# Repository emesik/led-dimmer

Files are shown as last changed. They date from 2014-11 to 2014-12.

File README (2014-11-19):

LED lighting dimmer

My aim was to create a dimmer for a long LED stripe which would go around a big room. I didn't
want to output raw PWM and have around 20m of cable acting as antenna, even though the frequency
could be low and theoretically harmless. For that reason the circuit has two modules:

	1. PWM generator with ATtiny85 microcontroller, two MOSFETs and potentiometer input
	2. LC filter with cutoff frequency just a bit above 150Hz

The final output is flat voltage depending on the PWM duty cycle. There is possibility, however, to
bypass the filter.

I used DTP-24 ferrite powder ring choke, rated up to 6A. That limits the circuit to 72W output.
The main MOSFET allows even 12A of continuous output at 25°C, so the max power depends mostly on
the choke you choose.

TODO:
	* So far tested it with tiny load. Must see how it behaves with a few meters of LED stripe.
	* The table of potentiometer to PWM duty cycle translation is still far from perfect and fails
	  to provide linear dimming.

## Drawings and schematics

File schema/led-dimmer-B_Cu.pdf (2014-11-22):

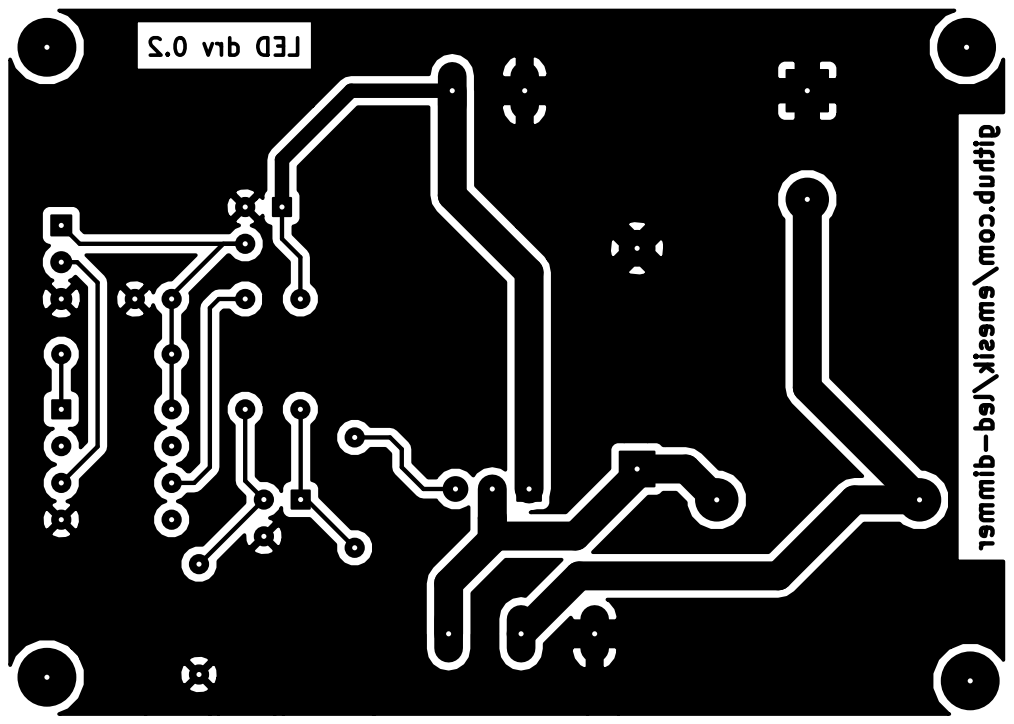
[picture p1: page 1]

github.com/emesik/led-dimmer LED drv 0.2

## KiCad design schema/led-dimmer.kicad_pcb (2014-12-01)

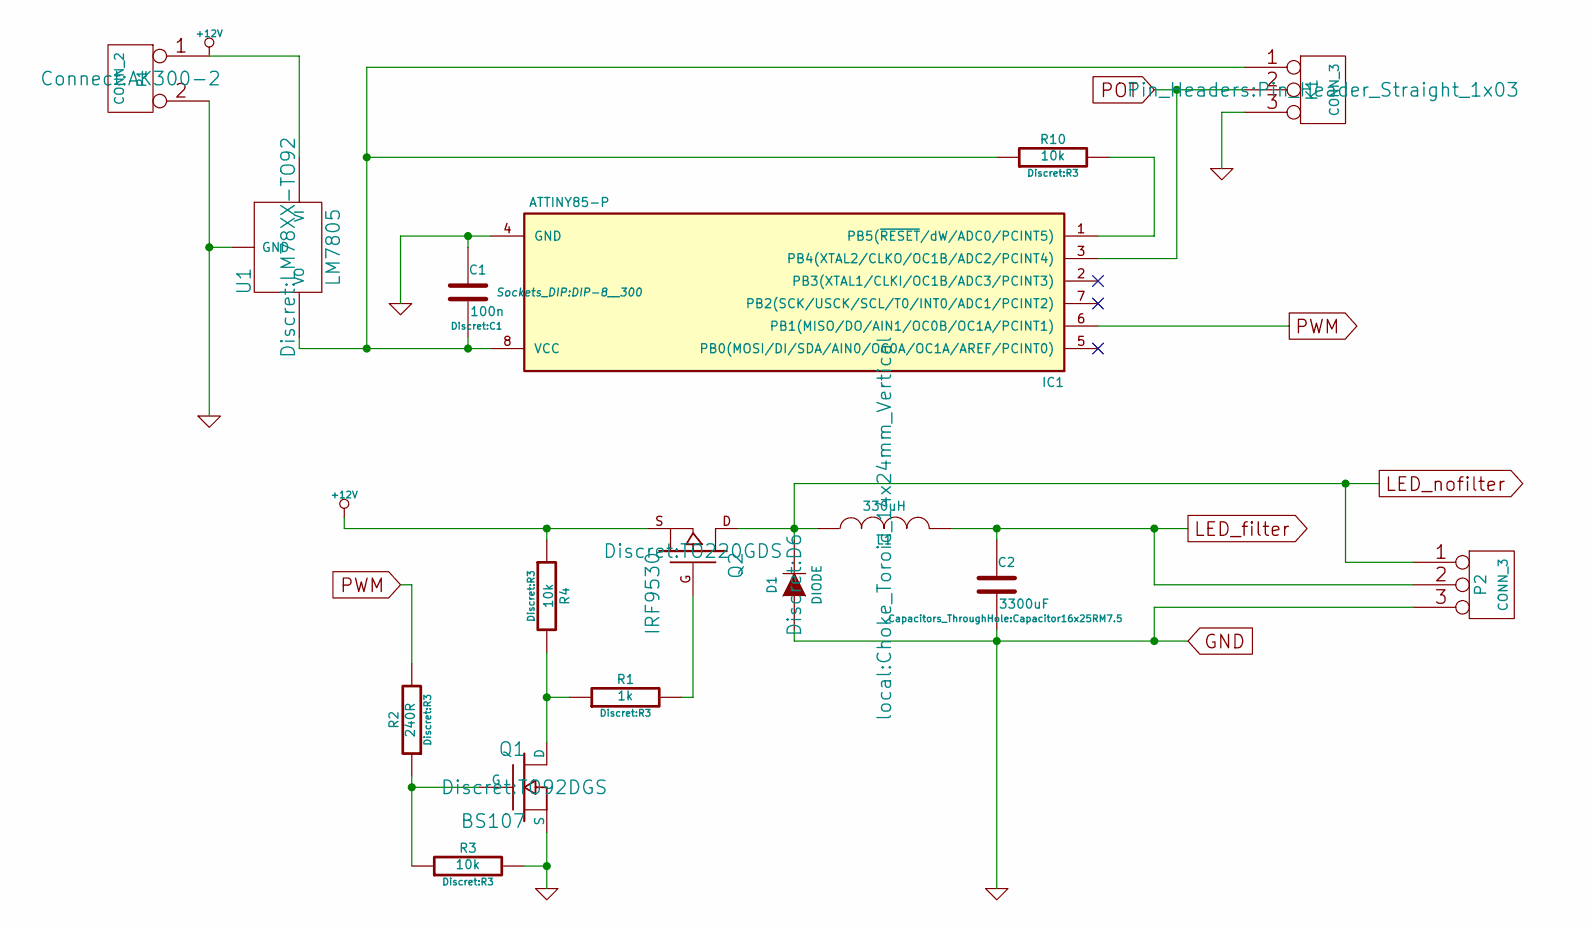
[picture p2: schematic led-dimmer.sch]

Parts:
C1: 100n; C1
C2: 3300uF; Capacitor16x25RM7.5
D1: DIODE; D6
IC1: ATTINY85-P; DIP-8__300
K1: CONN_3; Pin_Header_Straight_1x03
L1: 330uH; Choke_Toroid_14x24mm_Vertical
P1: CONN_2; AK300-2
P2: CONN_3; AK300-3
Q1: BS107; TO92DGS
Q2: IRF9530; TO220GDS
R1: 1k; R3
R2: 240R; R3
R3, R4, R10: 10k; R3
U1: LM7805; LM78XX-TO92

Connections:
+12V: P1.1, Q2.S, R4.1, U1.VI
GND: C1.1, C2.2, D1.1 (A), IC1.4 (GND), K1.3, P1.2 (PM), P2.3, Q1.S, R3.2, U1.GND
LED_filter: C2.1, L1.2, P2.2 (PM)
LED_nofilter: D1.2 (K), L1.1, P2.1, Q2.D
unnamed: C1.2, IC1.8 (VCC), K1.1, R10.1, U1.VO
unnamed: IC1.1 (PB5(~RESET~/dW/ADC0/PCINT5)), R10.2
unnamed: Q1.D, R1.1, R4.2
unnamed: Q1.G, R2.1, R3.1
unnamed: Q2.G, R1.2
POT: IC1.3 (PB4(XTAL2/CLKO/OC1B/ADC2/PCINT4)), K1.2 (PM)
PWM: IC1.6 (PB1(MISO/DO/AIN1/OC0B/OC1A/PCINT1)), R2.2

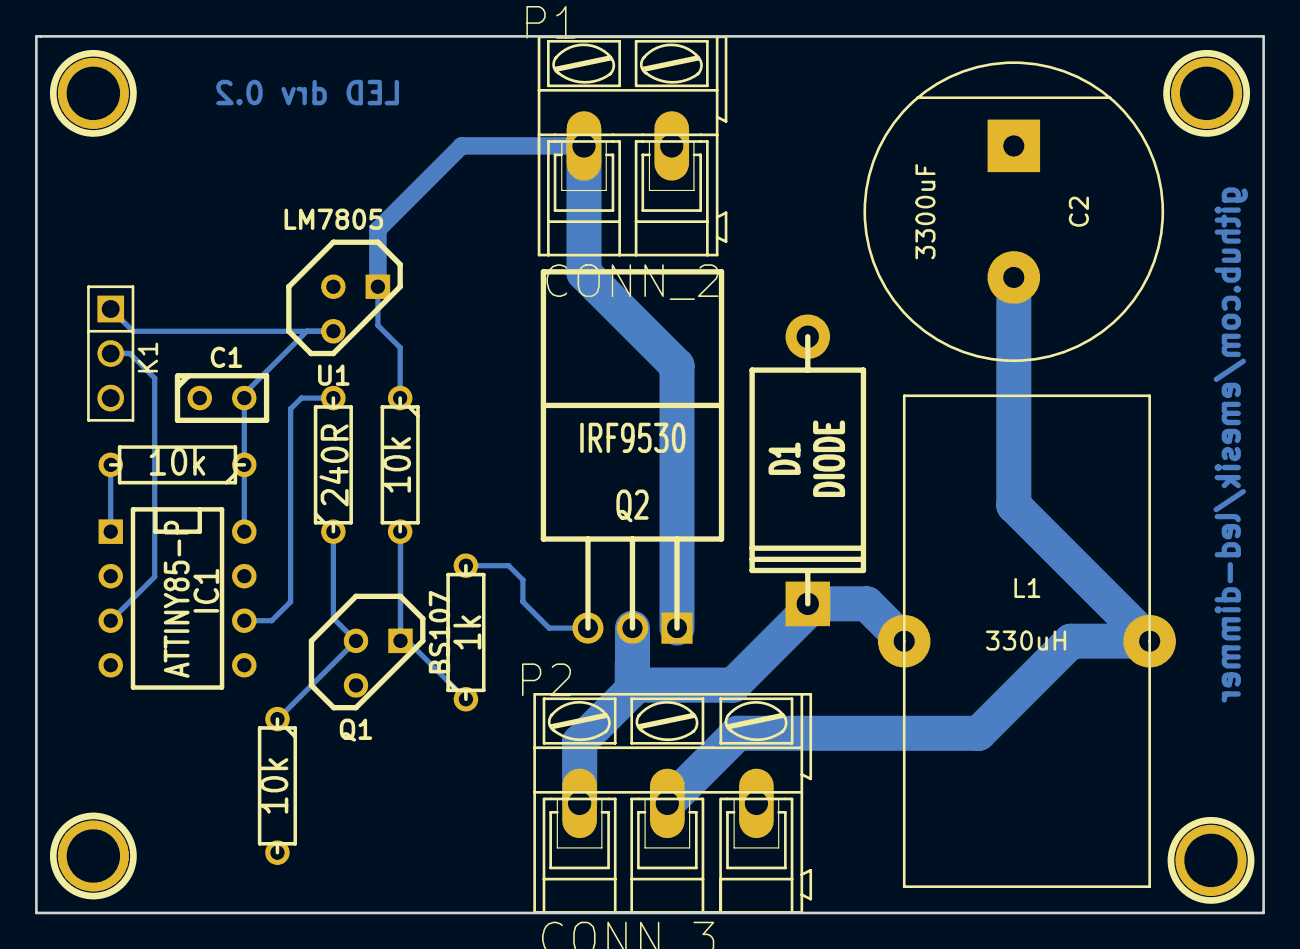
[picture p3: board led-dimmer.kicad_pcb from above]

Board: 2 copper layers, 70.0 x 50.0 mm, 16 parts (0 on the bottom side), 11 nets.

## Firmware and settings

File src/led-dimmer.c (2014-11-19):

#include <stdlib.h>
#include <avr/interrupt.h>
#include <avr/io.h>
#include <util/delay.h>

#include "trans.h"

/*****************************************************************************
 *
 * LED driver
 *
 *	PB1 (OC0B) - PWM output
 *	PB4 (ADC2) - potentiometer input
 *
 *	The PWM output is reverse of the input voltage from potentiometer.
 *	For 0V the duty cycle will be 100%, for Vcc it will be 0%.
 *	That allows for full force work when no potentiometer is present.
 *
 ****************************************************************************/


uint8_t read_potentiometer() {
	ADCSRA |= (1 << ADSC);
	while (ADCSRA & (1 << ADSC));
	return ADCH;
}

int main() {
	DDRB |= (1 << PB1);		// set PB1 as output
	DDRB &= ~(1 << PB4);	// set PB4 as input
	PORTB &= ~(1 << PB1);	// set PB1 low

	// phase correct PWM, inverting, no prescaler
	TCCR0A = (1 << COM0B1) | (1 << COM0B0) | (1 << WGM00);
	TCCR0B = (1 << CS00);
	OCR0B = 0xff;	// 0% duty cycle

	ADCSRA = (1 << ADEN)	// enable ADC
		| (1 << ADPS2) | (1 << ADPS1) | (1 << ADPS0);	// set 128 prescaler
	ADMUX = (1 << ADLAR) | (1 << MUX1);	// ADC2 (PB4) as input, 8bit precision

#ifdef DEBUG
	for (uint8_t i=0xff; i>0; i--) {
		OCR0B = i;
		_delay_ms(100);
	}
#endif

	while (1) {
		OCR0B = 0xff - pot2pwm[read_potentiometer()];
	}
	return 0;
}

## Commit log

2014-11-19 Initial release
    [led-driver.kicad_pcb, led-driver.sch]
2014-11-20 Update filenames to match project name
    [led-dimmer.kicad_pcb, led-dimmer.sch]
2014-11-22 Make PCB corrections
    [led-dimmer.sch]
2014-11-22 Plot rev 0.2 PCB
2014-12-01 New PCB which allows to connect bypassing LC filter
    [led-dimmer.kicad_pcb]
